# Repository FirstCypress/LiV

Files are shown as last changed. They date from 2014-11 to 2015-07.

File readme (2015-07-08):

LiV is a sensor expansion board that turns your Raspberry Pi model B or B+ into a modern indoor air quality monitoring device that measures CO2, temperature, humidity and air pressure. 

LiV software files are released under a MIT license. 
http://opensource.org/licenses/MIT

LiV hardware files are released under a CC BY-NC-SA 4.0 license. 
LiV case files are released under a CC BY-NC-SA 4.0 license. 
https://creativecommons.org/licenses/by-nc-sa/4.0/

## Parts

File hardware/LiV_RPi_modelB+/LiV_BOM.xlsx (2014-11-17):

Description | Digi-Key Part Number | Adafruit Part Number | CO2METER.COM | Quantity
CONN RECEPT 4POS | WM3002-ND |  |  | 5
CONN HEADER FMAL 26POS | S7081-ND |  |  | 1
CONN HEADER 4POS | WM4113-ND |  |  | 1
CONN HEADER FEMALE 4POS | S7002-ND |  |  | 1
CONN HEADER FEMALE 2POS .1" TIN | S7000-ND |  |  | 1
SWITCH TACTILE | 450-1662-ND |  |  | 1
CONN HEADER 20POS | 609-3221-ND |  |  | 1
RES 10K OHM 1/4W 5% CARBON FILM | CF14JT10K0CT-ND |  |  | 2
HEX STANDOFF M3 NYLON | 952-2185-ND |  |  | 2
MACHINE SCREW PAN SLOTTED M3 | 29341K-ND |  |  | 4
K30 CO2 |  |  | SE 0018 | 1
DHT22 TEMP/HUMIDITY |  | 385 |  | 1
BMP180 AIR PRESSURE |  | 1603 |  | 1
STANDARD LCD16x2 |  | 181 |  | 1
I2C LCD BACKPACK |  | 292 |  | 1
FEMALE TO FEMALE JUMPER WIRE |  | 1949 |  | 1

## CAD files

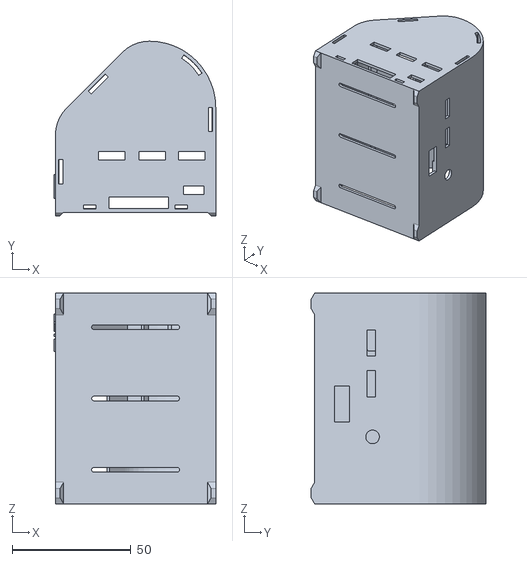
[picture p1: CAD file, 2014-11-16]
case/3D_printed_LiV_RPi_model_B/case_mid.STL
68.0 x 73.5 x 88.8

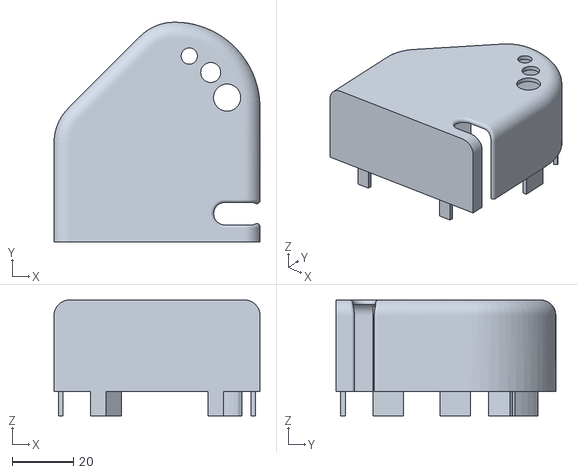
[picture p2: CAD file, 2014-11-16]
case/3D_printed_LiV_RPi_model_B/case_right.STL
67.5 x 72.0 x 38.0

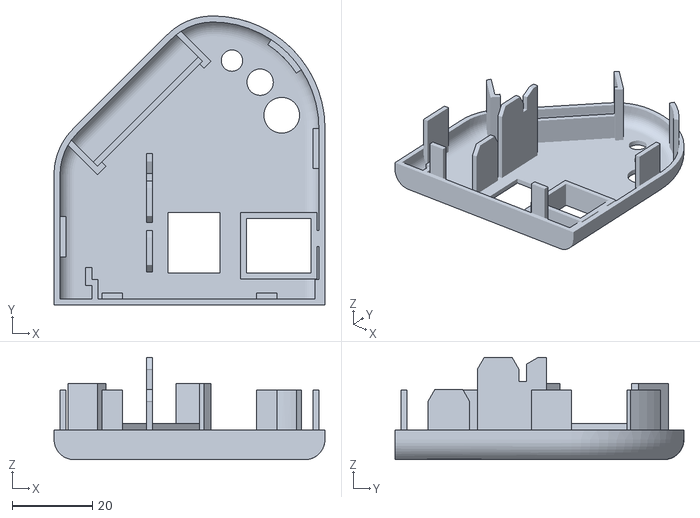
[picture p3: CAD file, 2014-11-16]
case/3D_printed_LiV_RPi_model_B/case_left.STL
67.5 x 72.0 x 25.5

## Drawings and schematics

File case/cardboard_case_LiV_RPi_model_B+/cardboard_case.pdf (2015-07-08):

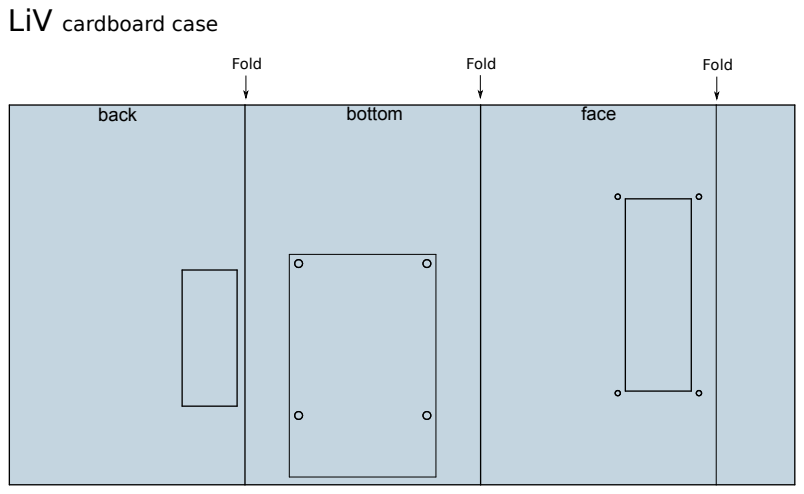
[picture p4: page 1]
back; bottom; face; Fold

LiV cardboard case

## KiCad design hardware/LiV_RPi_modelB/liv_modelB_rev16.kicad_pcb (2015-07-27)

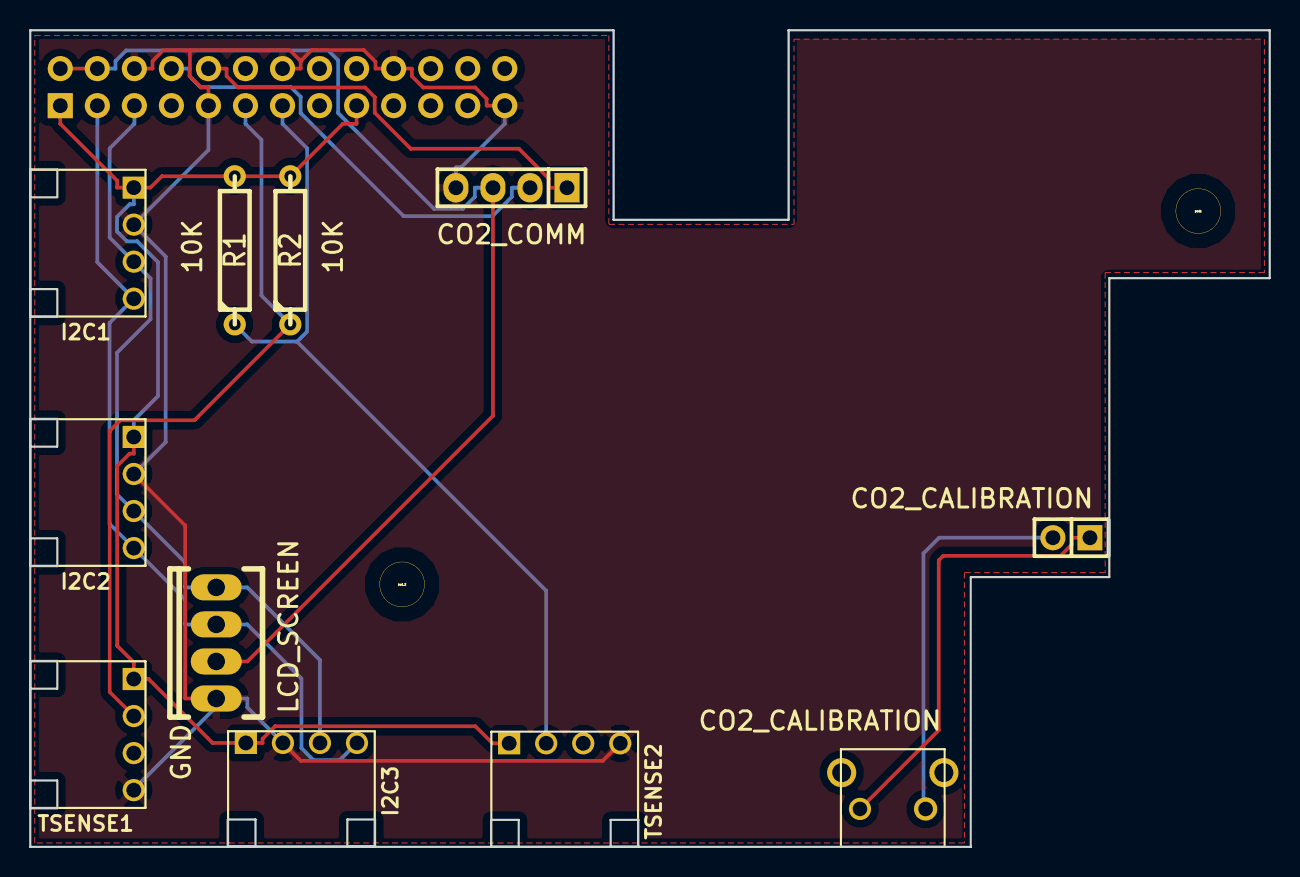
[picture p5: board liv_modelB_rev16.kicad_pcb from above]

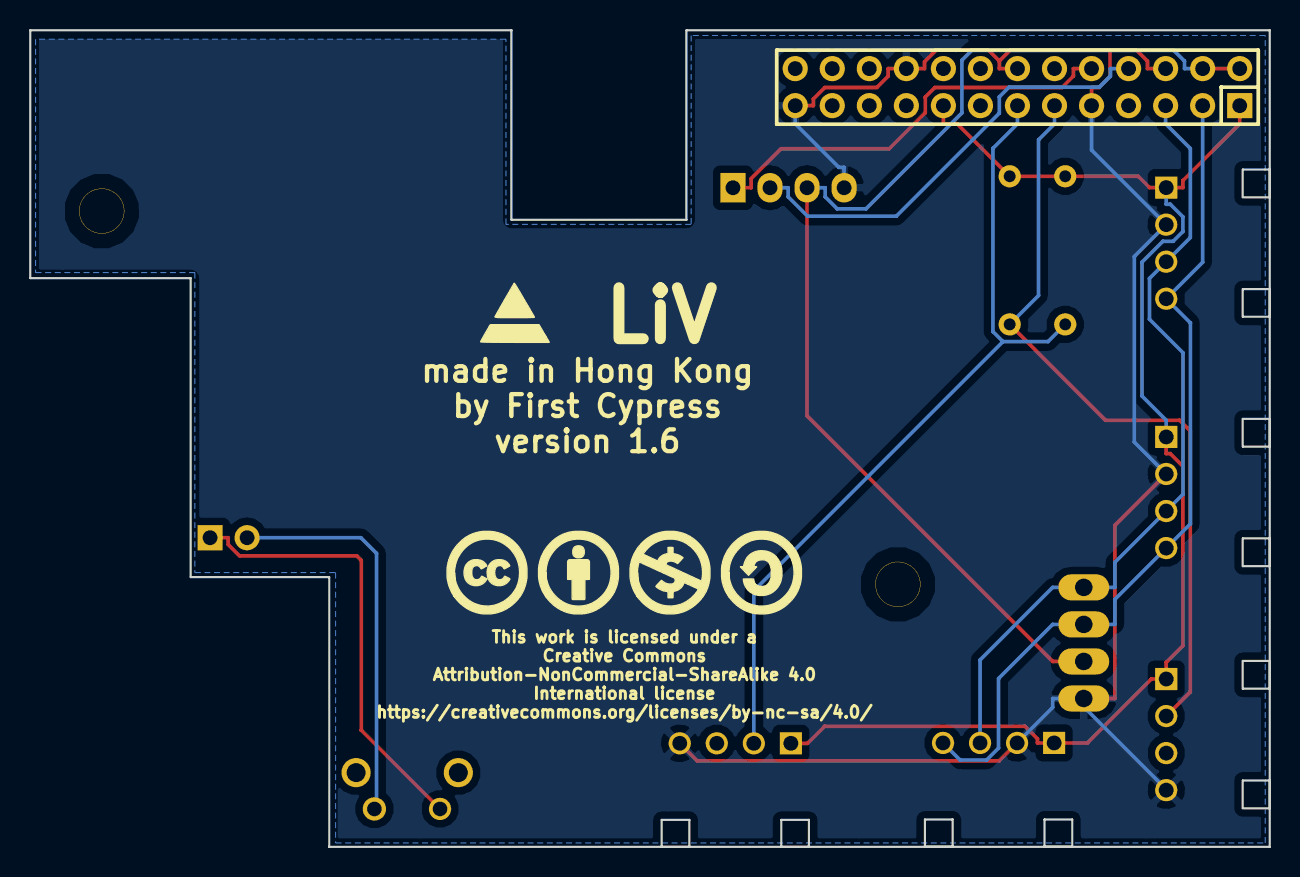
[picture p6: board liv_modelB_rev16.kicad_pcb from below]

Board: 2 copper layers, 85.0 x 56.0 mm, 15 parts (2 on the bottom side), 11 nets.

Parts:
P1: CONN_13X2; Socket_Strip_Straight_2x13
P3: LCD_SCREEN; Socket_MOLEX-KK-RM2-54mm_Lock_4pin_straight
P4: CO2_CALIBRATION; Socket_Strip_Straight_2x01
P5: CO2_COMM; Socket_Strip_Straight_1x04
P6: I2C1; CONNECTOR_MOLEX_4PIN_RIGHT_ANGLE
P7: I2C2; CONNECTOR_MOLEX_4PIN_RIGHT_ANGLE
P8: TSENSE2; CONNECTOR_MOLEX_4PIN_RIGHT_ANGLE
P9: TSENSE1; CONNECTOR_MOLEX_4PIN_RIGHT_ANGLE
P10: I2C3; CONNECTOR_MOLEX_4PIN_RIGHT_ANGLE
R1, R2: 10k; R4
SW1: CO2_CALIBRATION; SWITCH_TACT_RIGHT_ANGLE
cc_by_nc_sa_logo_only: LOGO; cc_by_nc_sa_logo_only
pad1: 1pin
pad_2: 1pin

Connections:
+3.3V: P1.1, P1.17, P6.1, P7.1, P8.1, P9.1, P10.1, R1.2, R2.2
+5V: P1.2, P1.4, P3.2, P5.3
/GPIO_2: P1.3, P3.3, P6.4, P7.4, P10.4
/GPIO_3: P1.5, P3.4, P6.3, P7.3, P10.3
/GPIO_14: P1.8, P5.2
/GPIO_15: P1.10, P5.1
/GPIO_17: P1.11, P9.2, R2.1
/GPIO_27: P1.13, P8.2, R1.1
GND: P1.6, P1.9, P1.14, P1.20, P1.25, P3.1, P5.4, P6.2, P7.2, P8.4, P9.4, P10.2
unnamed: P4.1, SW1.2
unnamed: P4.2, SW1.1

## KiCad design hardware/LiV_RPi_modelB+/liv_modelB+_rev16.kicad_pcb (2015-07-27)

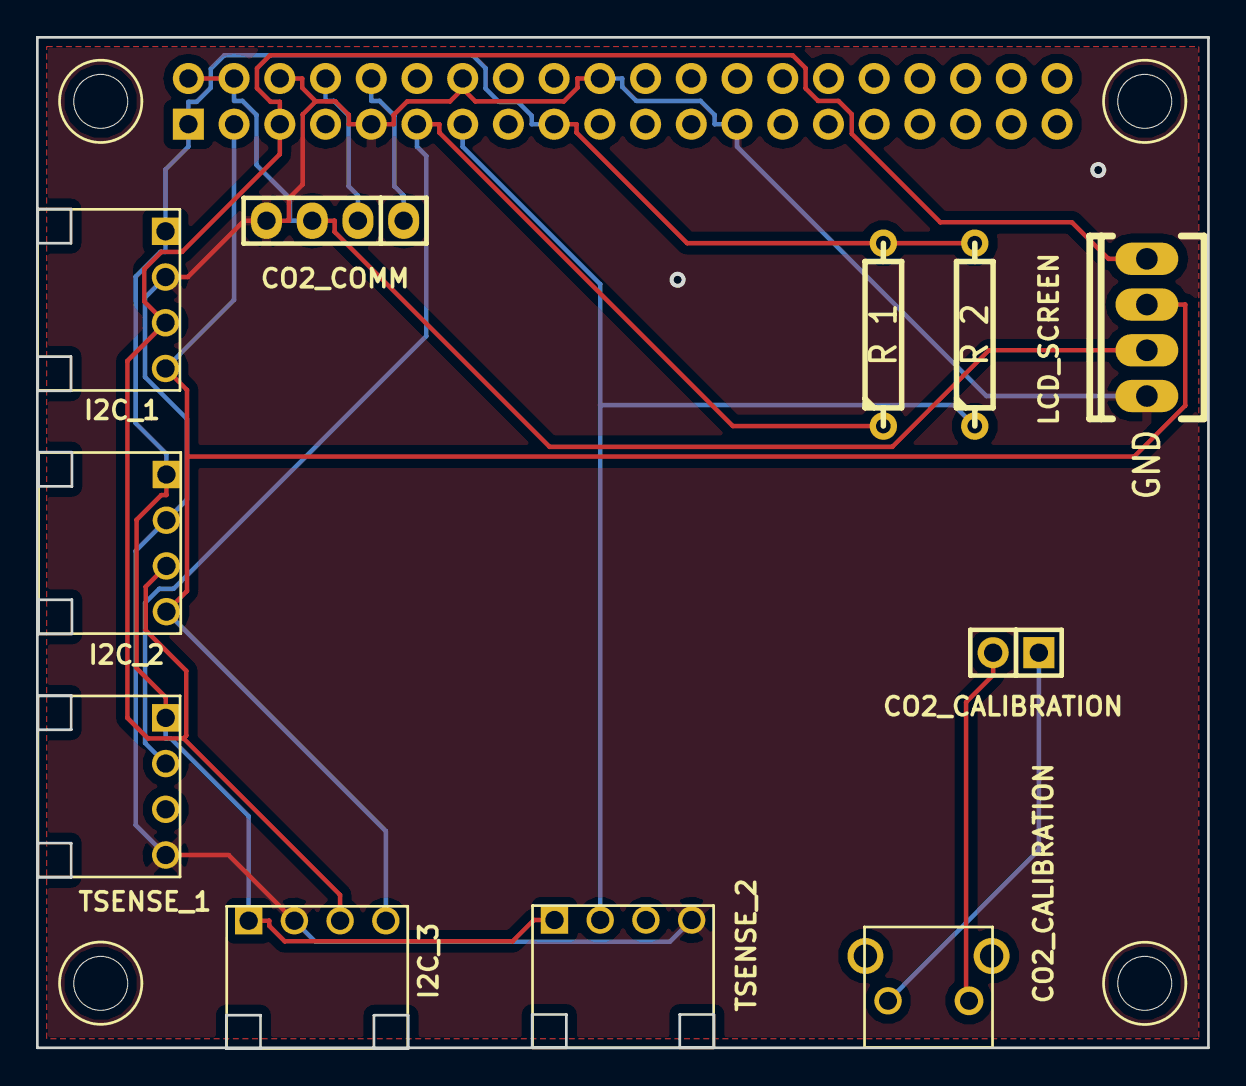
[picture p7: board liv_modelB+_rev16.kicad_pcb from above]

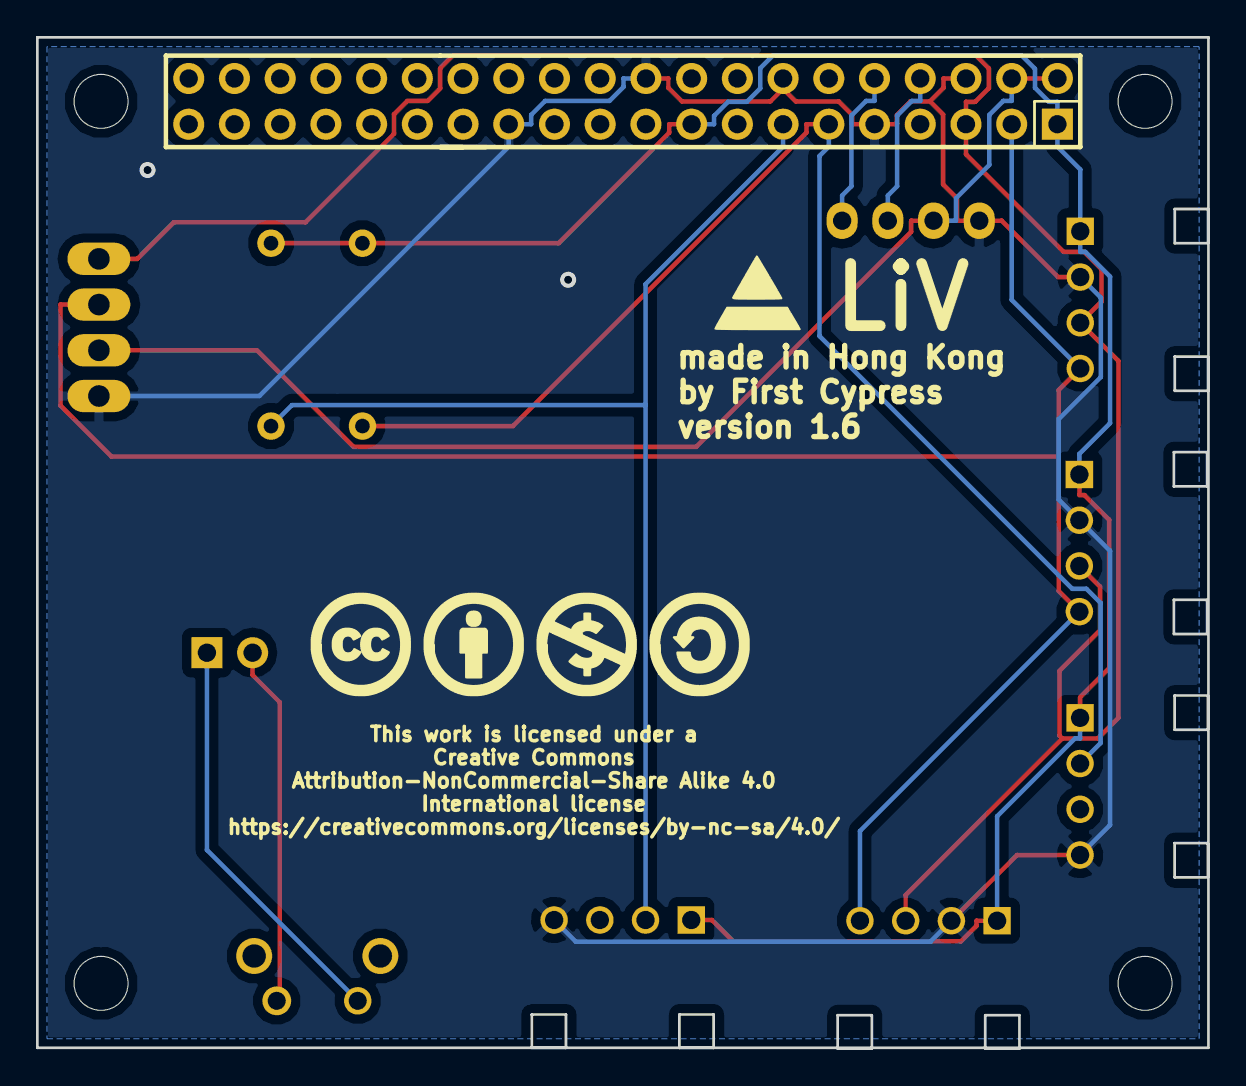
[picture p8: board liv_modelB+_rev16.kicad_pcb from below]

Board: 2 copper layers, 65.1 x 56.1 mm, 18 parts (3 on the bottom side), 11 nets.

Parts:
1_MNT_HOLE_RPI_PLUS, 2_MNT_HOLE_RPI_PLUS, 3_MNT_HOLE_RPI_PLUS, 4_MNT_HOLE_RPI_PLUS: mountingHole
R 1, R 2: 10k; R4
cc_by_nc_sa_logo_only: LOGO; cc_by_nc_sa_logo_only
co2_calibration1: CO2_CALIBRATION; SWITCH_TACT_RIGHT_ANGLE
co2_comm: CO2_COMM; Socket_Strip_Straight_1x04
co2_reset1: CO2_CALIBRATION; Socket_Strip_Straight_2x01
i2c_1: I2C_1; CONNECTOR_MOLEX_4PIN_RIGHT_ANGLE
i2c_2: I2C_2; CONNECTOR_MOLEX_4PIN_RIGHT_ANGLE
i2c_3: I2C_3; CONNECTOR_MOLEX_4PIN_RIGHT_ANGLE
liv_cone: LOGO; LivCypressOnlyLogo
rpi40: CONN_20X2; Socket_Strip_Straight_2x13
screen: LCD_SCREEN; Socket_MOLEX-KK-RM2-54mm_Lock_4pin_straight
temp_1: TSENSE_1; CONNECTOR_MOLEX_4PIN_RIGHT_ANGLE
temp_2: TSENSE_2; CONNECTOR_MOLEX_4PIN_RIGHT_ANGLE

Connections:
+3.3V: R 1.2, R 2.2, i2c_1.1, i2c_2.1, i2c_3.1, rpi40.1, rpi40.17, temp_1.1, temp_2.1
+5V: co2_comm.3, rpi40.2, rpi40.4, screen.2
/GPIO_2: i2c_1.4, i2c_2.4, i2c_3.4, rpi40.3, screen.3
/GPIO_3: i2c_1.3, i2c_2.3, i2c_3.3, rpi40.5, screen.4
/GPIO_14: co2_comm.2, rpi40.8
/GPIO_15: co2_comm.1, rpi40.10
/GPIO_17: R 1.1, rpi40.11, temp_1.2
/GPIO_27: R 2.1, rpi40.13, temp_2.2
GND: co2_comm.4, i2c_1.2, i2c_2.2, i2c_3.2, rpi40.6, rpi40.9, rpi40.14, rpi40.20, rpi40.25, screen.1, temp_1.4, temp_2.4
unnamed: co2_calibration1.1, co2_reset1.2
unnamed: co2_calibration1.2, co2_reset1.1

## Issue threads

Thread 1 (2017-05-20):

Need update Adafruit DHT library for RPI3

cawa0505, 2017-05-20:
Because the cpuinfo in Raspberry Pi 3 has changed, need update the platform_detect.py

alfredc333, 2017-06-01:
Thanks for raising this issue.
I removed the old Adafruit libraries stored in my github repo with README files instructing the user to use the most recent version of the Adafruit Python libraries.

Closed 2017-06-01.

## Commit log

2014-11-16 added case repository v1_00
    [case_left.STL, case_mid.STL, case_right.STL]
2014-11-16 add hardware directory
    [LiV.kicad_pcb, LiV.sch]
2014-11-17 added BOM
    [LiV_BOM.xlsx]
2015-01-08 add STL files in the case directory
    [case_left.STL, case_mid.STL, case_right.STL]
2015-01-08 clean up old STL files
    [case_left.STL, case_mid.STL, case_right.STL]
2015-01-08 create new directory to organize code
    [LiV.kicad_pcb, LiV.sch, LiV_BOM.xlsx]
2015-01-08 added files for modelB+
    [LiV_2.sch, LiV_BOM.xlsx, LiV_modelBPlus.kicad_pcb]
2015-03-20 added experimental devicehive code
    [rpi_example.cfg, virtual_led_example.cfg]
2015-07-08 added cardboard case, clean up files
    [case_left.STL, case_mid.STL, case_right.STL]
2015-07-08 clean up files
    [case_left.STL, case_mid.STL, case_right.STL]
2015-07-09 added xively sample code
2015-07-27 added latest PCB files
    [LiV.kicad_pcb, LiV.sch, LiV_2.sch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]
2015-09-05 added data.sparkfun and analog.io IoT sample code
2015-09-10 fix for livLCD crash without CO2 sensor onboard
2015-10-06 added directory iotConnectors
    [rpi_example.cfg, virtual_led_example.cfg]
2015-10-06 removed directory experimental
    [rpi_example.cfg, virtual_led_example.cfg]

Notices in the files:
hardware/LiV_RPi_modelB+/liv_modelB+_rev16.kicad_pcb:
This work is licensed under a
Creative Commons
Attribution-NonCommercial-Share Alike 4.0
